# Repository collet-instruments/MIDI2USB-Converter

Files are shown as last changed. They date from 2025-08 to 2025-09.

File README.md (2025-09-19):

# 🎹 MIDI2USB Converter

<p align="center">
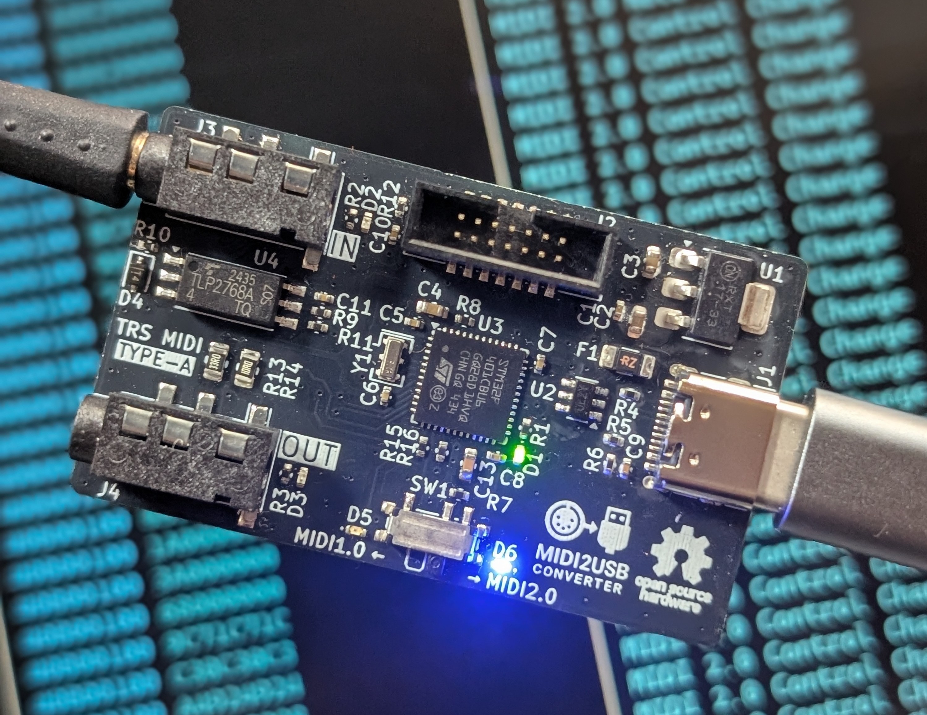
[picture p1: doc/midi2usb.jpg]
MIDI2USB Logo
  
</p>

<p align="center">
  
  
  
  
  
  
  
  
</p>

<p align="center">
  <strong>STM32F401-based USB MIDI converter supporting both MIDI 1.0 and MIDI 2.0 protocols.</strong>
</p>

## ✨ Features
- 🎵 **Dual Protocol Support**: MIDI 1.0 and MIDI 2.0 protocols
- 🔌 **USB Device Classes**: 
  - MIDI 1.0: Standard USB MIDI Class
  - MIDI 2.0: USB MIDI 2.0 Class with UMP support
- 🔄 **Dynamic Mode Switching**: Automatic detection based on SETUP switch
- 📦 **UMP (Universal MIDI Packet)**: Full support for MIDI 2.0 messaging
- 🔍 **MIDI-CI**: MIDI-CI v1.2 support
- 💡 **Visual Feedback**: LED status indicators
  - Red LED: USB MIDI 1.0 mode indicator
  - Blue LED: USB MIDI 2.0 mode indicator
- ⚡ **Real-time OS**: FreeRTOS-based multitasking
- 🔗 **UART Bridge**: Hardware TRS MIDI Type-A (3.5mm jack) interface support

## 📖 Usage

### Using USB MIDI1.0 Mode

  MIDI1.0 mode

- Switch SETUP (SW1) to MIDI1.0 and connect the USB Type-C port (J1) to a USB host
- The red LED (D5) will light up
- MIDI packets received at the MIDI IN port (J3) will be sent to the USB host
- Similarly, MIDI packets sent from the USB host will be output to the MIDI OUT port (J4)
- Data transfer status can be monitored via indicator LEDs (D2, D3) for both MIDI IN and MIDI OUT ports

### Using USB MIDI2.0 Mode

  MIDI2.0 mode

- Switch SETUP (SW1) to MIDI2.0 and connect the USB Type-C port (J1) to a USB host
- The blue LED (D6) will light up
- MIDI packets (MIDI1.0 byte stream) received at the MIDI IN port (J3) are converted to USB MIDI2.0 UMP (Universal MIDI Packet) and sent to the USB host
  - At this time, MIDI1.0 Voice Messages are extended to MIDI2.0 Protocol (UMP Message Type 4)
  - Similarly, MIDI2.0 UMP sent from the USB host is converted to MIDI1.0 byte stream and output to the MIDI OUT port (J4)
    - Since MIDI2.0 Protocol sent from the USB host is converted to MIDI1.0 Protocol, some data may be lost
- Data transfer status can be monitored via indicator LEDs (D2, D3) for both MIDI IN and MIDI OUT ports
- Some operating systems do not support USB MIDI2.0 drivers, in which case MIDI2.0 mode may not be available. Please use MIDI1.0 mode in such cases.

## 🔄 Protocol Conversion Rules

### MIDI 1.0 → MIDI 2.0 Conversion
The converter performs a 2-stage conversion process:
1. **Stage 1**: MIDI 1.0 byte stream → UMP (MIDI 1.0 Protocol)
2. **Stage 2**: UMP (MIDI 1.0 Protocol) → UMP (MIDI 2.0 Protocol)

**Key transformations**:
- **Resolution Enhancement**: 7-bit values are scaled up to 16-bit or 32-bit
  - Note velocity: 7-bit → 16-bit (e.g., 127 → ~65024)
  - Control Change values: 7-bit → 32-bit
  - Pitch Bend: 14-bit → 32-bit
- **Message Type**: Voice Messages are upgraded to UMP Message Type 4 (MIDI 2.0 Protocol)

### MIDI 2.0 → MIDI 1.0 Conversion
Direct conversion from UMP to MIDI 1.0 byte stream:

**Key transformations**:
- **Resolution Reduction**: High-resolution values are scaled down
  - Control values: 32-bit → 7-bit
- **Special handling for Note On velocity 0**:
  - In MIDI 2.0, Note On with velocity 0 remains a Note On
  - During conversion, velocity 0 is changed to 1 to prevent unintended Note Off behavior in MIDI 1.0
- **Data Loss**: MIDI 2.0-specific features (extended CC, per-note controllers) cannot be represented in MIDI 1.0

### Conversion Examples
- **MIDI 1.0 Note On**: `90 3C 64` (Ch1, Middle C, Velocity 100)
  → **MIDI 2.0 UMP**: `40902C00 32800000` (Velocity ≈ 51200)
  
- **MIDI 2.0 Note On**: Velocity 32768 (50% intensity)
  → **MIDI 1.0**: `90 3C 40` (Velocity 64, precision reduced)

## ⚠️ Caution

- The IN/OUT terminals of this product are **TRS MIDI Type-A only**. Do not use other types of cables.  
- Make sure not to confuse IN and OUT connections. Incorrect wiring may cause reverse current and damage your equipment.  
- This product is designed for **USB Type-C 5V power supply only**. Do not apply any other voltage.  
- The product may be damaged by static electricity. Please handle with proper ESD precautions.  
- Modifications or improper soldering may cause malfunction or accidents.  
- Do not use in environments with high temperature, high humidity, direct sunlight, or condensation.  
- Compatibility with all MIDI devices is **not guaranteed**.  

## 📜 Disclaimer

- This product is provided for **electronic hobby, educational, and research purposes**.  
- It is **not a consumer-ready product** and has **not been certified** under any safety standards or regulations (such as **PSE, Radio Act certification, CE, UL**, etc.).  
- By purchasing and using this product, you agree to the following terms:

### Use at Your Own Risk
- We accept no responsibility for any damage to equipment, personal injury, fire, data loss, or any other loss or accident resulting from the use of this product.

### Limitations of Use
- Do not use this product in industrial equipment, medical devices, safety systems, or any other applications where human life or property may be at risk.  
- Continuous long-term operation or use under heavy loads is not intended.

### Modification and Connections
- We are not responsible for any malfunction or damage caused by modification of this product or connection to unintended devices.

### Returns and Warranty
- If a manufacturing defect is confirmed, we will provide a replacement or refund.  
- No other warranties or guarantees are offered.

## ⚙️ Modification and Collaboration

- This product is provided as **open hardware**.  
  You are free to modify, reuse, or build upon the circuit and firmware.  
  However, **we cannot guarantee the operation or safety of modified versions**.  

- We welcome contributions from developers and users who wish to improve the design.  
  Please feel free to share feedback, modifications, or enhancement ideas.  

## 🛠️ Build Requirements

- ARM GCC toolchain (arm-none-eabi-gcc)
- CMake (3.22 or later)
- Ninja build system
- Git (for submodules)

## 📥 Getting Started

### Clone the Repository

```bash
git clone --recursive https://github.com/collet-instruments/MIDI2USB-Converter.git
cd MIDI2USB-Converter

# If you already cloned without --recursive, initialize submodules
git submodule init
git submodule update
```
### IDE Integration

**VS Code**: Use CMake extension for building and debugging with ST-Link.

- [STM32 VS Code extension](https://www.st.com/content/st_com/ja/campaigns/stm32-vs-code-extension-z11.html) makes setup easy.

## 🔨 Building

### Using CMake

```bash
# Configure the project
cmake --preset Debug

# Build the firmware
cmake --build --preset Debug

# The output files will be in build/Debug/
```
### Build Configurations

The project supports multiple build configurations:

- **Debug**: Development build with debug symbols (default)
- **Release**: Optimized build for production (-O2 optimization)
- **RelWithDebInfo**: Release build with debug info
- **MinSizeRel**: Size-optimized build (-Os optimization)

## 🧪 Testing

The project includes a comprehensive unit test suite using Unity framework.

### Running Tests

```bash
# Run all tests
cd test
make test

# Run specific test
make test-mode_manager

# Run tests with coverage
make clean
make COVERAGE=1
make test
```

## ✅ Code Quality

### Code Formatting

The project uses clang-format for code formatting. Configuration is in `.clang-format`.

```bash
# Format code
clang-format -i Core/Src/*.c Core/Inc/*.h

# Check formatting without modifying files
clang-format --dry-run --Werror Core/Src/*.c Core/Inc/*.h
```

### Static Analysis

```bash
# Run cppcheck
cppcheck --enable=warning,style,performance,portability \
  -I Core/Inc \
  Core/Src/
```

### CI/CD

GitHub Actions automatically runs on every push and pull request:

#### Workflows:
- **ci.yml**: Main CI pipeline
  - Builds STM32 firmware  
  - Runs all unit tests
  - Uploads firmware artifacts
  
- **code-quality.yml**: Code quality checks
  - Static analysis with cppcheck
  - Code formatting verification with clang-format
  
- **release.yml**: Automated releases
  - Triggers on version tags (v*)
  - Creates GitHub releases with firmware binaries

## 📁 Project Structure

```
├── Core/               # Application source code
├── Drivers/            # STM32 HAL and CMSIS drivers
├── submodules/         # External dependencies
│   ├── FreeRTOS-Kernel/
│   ├── tinyusb/
│   ├── AM_MIDI2.0Lib/
│   ├── tusb_ump/
│   └── Unity/
├── test/               # Unit tests (Unity framework)
│   ├── src/            # Test source files
│   ├── mock/           # Mock implementations
│   └── include/        # Test headers
├── ci/                 # CI/CD scripts
└── .github/            # CI/CD workflows
```

## 📦 Submodules

This project uses the following Git submodules:

| Submodule | Repository URL | Description |
|---|---|---|
| **FreeRTOS-Kernel** | https://github.com/FreeRTOS/FreeRTOS-Kernel.git | FreeRTOS kernel files only |
| **tinyusb** | https://github.com/hathach/tinyusb.git | An open source cross-platform USB stack for embedded system |
| **tusb_ump** | https://github.com/midi2-dev/tusb_ump | USB MIDI 2.0 tinyUSB Device driver with backwards compatibility to USB MIDI 1.0 |
| **AM_MIDI2.0Lib** | https://github.com/midi2-dev/AM_MIDI2.0Lib | A MIDI 2.0 C++ Library |
| **Unity** | https://github.com/ThrowTheSwitch/Unity.git | Simple unit testing for C |

## 🔧 Hardware

### 🎛️ Microcontroller
- **MCU**: STM32F401CBU6 (ARM Cortex-M4, 84MHz)
- **Flash**: 256KB
- **RAM**: 64KB

### 🔌 Interfaces
- **USB**: Full-Speed USB 2.0 (12Mbps)
- **UART**: MIDI serial interface (31.25 kbaud)
  - TX: PA2 (USART2_TX)
  - RX: PA3 (USART2_RX)
- **DEBUG**: ST-Link support (J2 connector)

### 📍 GPIO Pins
- **Mode Selection**: PA5 (SETUP pin)
  - High: USB MIDI 2.0 mode
  - Low: USB MIDI 1.0 mode
- **LEDs**:
  - M1LED: PA4 - USB MIDI 1.0 mode indicator
  - M2LED: PA6 - USB MIDI 2.0 mode indicator

### ⚡ Power
- Powered via USB (5V)
- 3.3V internal operation

## 💻 Development

### Running Tests Locally
```bash
# Quick test before pushing
./ci/test-ci-locally.sh

# Install optional CI tools
./ci/install-ci-tools.sh
```

### Debugging

1. **VS Code**: Use CMake extension and ST-Link for debugging
2. **OpenOCD**: Manual debugging with GDB

- Connect the J2 connector (NRST, SYS_SWCLK, SYS_SWDIO) to ST-Link for debugging. USART1 is also available for printf debugging.

## 🤝 Contributing

We welcome contributions! Please see [CONTRIBUTING.md](CONTRIBUTING.md) for details on:
- How to submit issues
- How to submit pull requests
- Code style guidelines
- Development setup

## 📜 Code of Conduct

This project adheres to a Code of Conduct. By participating, you are expected to uphold this code. Please see [CODE_OF_CONDUCT.md](CODE_OF_CONDUCT.md) for details.

## 📄 License

This project is licensed under the MIT License - see the [LICENSE](LICENSE) file for details.

**Hardware Design**: All hardware design files including schematics, PCB layouts, and manufacturing files in the `hardware/` directory are also covered under the same MIT License.

### Third-party Licenses

This project uses the following open-source libraries:
- **FreeRTOS-Kernel**: MIT License
- **TinyUSB**: MIT License
- **AM_MIDI2.0Lib**: MIT License
- **Unity Test Framework**: MIT License
- **STM32 HAL Drivers**: BSD 3-Clause License (STMicroelectronics)

## 👥 Authors and Acknowledgments

- USB MIDI 2.0 implementation based on TinyUSB and AM_MIDI2.0Lib
- STM32 HAL drivers by STMicroelectronics
- Special thanks to all contributors

## 💬 Support

For questions and support:
- Open an issue on GitHub
- Check existing issues and discussions
- See documentation in the repository

## 📝 Copyright

Copyright © 2025 Collet Instruments. All rights reserved.

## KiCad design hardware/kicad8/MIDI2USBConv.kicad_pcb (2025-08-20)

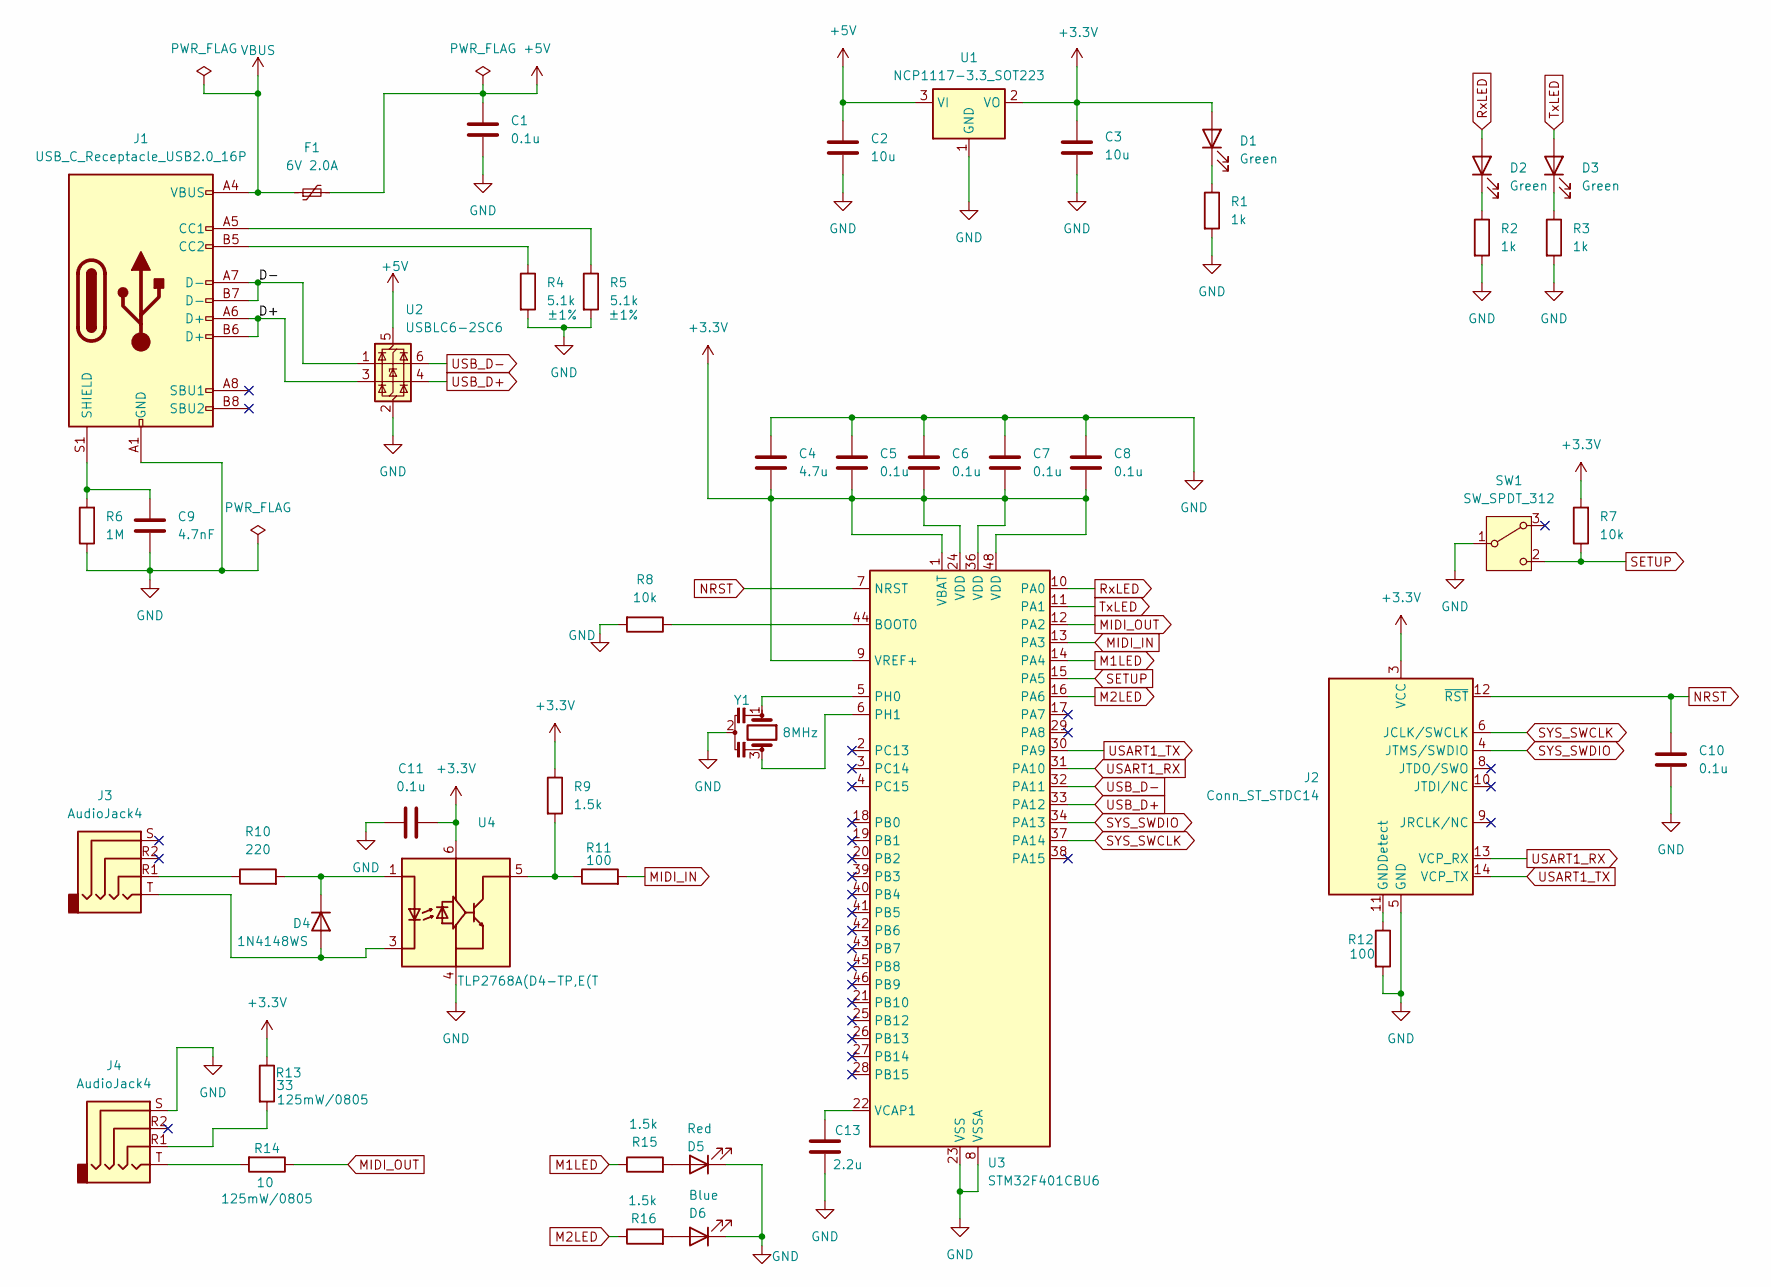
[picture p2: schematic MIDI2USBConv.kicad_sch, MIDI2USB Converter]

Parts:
C1, C5, C6, C7, C8, C10, C11: 0.1u; C_0402_1005Metric; LCSC C1525
C2, C3: 10u; C_0603_1608Metric; LCSC C1691
C4: 4.7u; C_0603_1608Metric; LCSC C1705
C9: 4.7nF; C_0402_1005Metric; LCSC C1538
C13: 2.2u; C_0603_1608Metric; LCSC C1607
D1, D2, D3: Green; LED_0402_1005Metric; LCSC C434449
D4: 1N4148WS; D_SOD-323; LCSC C2128
D5: Red; LED_0402_1005Metric; LCSC C264407
D6: Blue; LED_0402_1005Metric; LCSC C131223
F1: 6V 2.0A; Fuse_1206_3216Metric; LCSC C20803
J1: USB_C_Receptacle_USB2.0_16P; USB_C_Receptacle_G-Switch_GT-USB-7010ASV; LCSC C2988369
J2: Conn_ST_STDC14; STDC14_SMD; LCSC C42455944
J3, J4: AudioJack4; Jack_3.5mm_PJ320D_Horizontal; LCSC C95562
R1, R2, R3: 1k; R_0402_1005Metric; LCSC C11702
R4, R5: 5.1k; R_0402_1005Metric; LCSC C25905
R6: 1M; R_0402_1005Metric; LCSC C26083
R7, R8: 10k; R_0402_1005Metric; LCSC C25531
R9, R15, R16: 1.5k; R_0402_1005Metric; LCSC C25867
R10: 220; R_0402_1005Metric; LCSC C25091
R11, R12: 100; R_0402_1005Metric; LCSC C25076
R13: 33; R_0805_2012Metric; LCSC C17634
R14: 10; R_0805_2012Metric; LCSC C17415
SW1: SW_SPDT_312; SW_SPDT_PCM12; LCSC C221841
U1: NCP1117-3.3_SOT223; SOT-223-3_TabPin2; LCSC C26537
U2: USBLC6-2SC6; SOT-23-6; LCSC C5310974
U3: STM32F401CBU6; QFN-48-1EP_7x7mm_P0.5mm_EP5.6x5.6mm; LCSC C118825
U4: TLP2768A(D4-TP,E(T; SO-6L_10x3.84mm_P1.27mm; LCSC C5370532
Y1: 8MHz; Resonator_SMD_Murata_CSTxExxV-3Pin_3.0x1.1mm; LCSC C341524

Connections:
+3.3V: C3.1, C4.2, C5.2, C6.2, C7.2, C8.2, C11.2, D1.2 (A), J2.3 (VCC), R7.2, R9.1, R13.1, U1.2 (VO), U3.1 (VBAT), U3.9 (VREF+), U3.24 (VDD), U3.36 (VDD), U3.48 (VDD), U4.6 (VDD)
+5V: C1.1, C2.1, F1.2, U1.3 (VI), U2.5 (VBUS)
/D+: J1.A6 (D+), J1.B6 (D+), U2.3 (I/O2)
/D-: J1.A7 (D-), J1.B7 (D-), U2.1 (I/O1)
GND: C1.2, C2.2, C3.2, C4.1, C5.1, C6.1, C7.1, C8.1, C9.1, C10.2, C11.1, C13.2, D5.1 (K), D6.1 (K), J1.A1 (GND), J1.A12 (GND), J1.B1 (GND), J1.B12 (GND), J2.5 (GND), J2.7 (GND), J4.S, R1.2, R2.2, R3.2, R4.2, R5.2, R6.1, R8.2, R12.2, SW1.1 (B), U1.1 (GND), U2.2 (GND), U3.8 (VSSA), U3.23 (VSS), U3.35 (VSS), U3.47 (VSS), U3.49 (VSS), U4.4 (GND), Y1.2
M1LED: R15.1, U3.14 (PA4)
M2LED: R16.1, U3.16 (PA6)
MIDI_IN: R11.2, U3.13 (PA3)
MIDI_OUT: R14.1, U3.12 (PA2)
NRST: C10.1, J2.12 (~RST), U3.7 (NRST)
unnamed: D1.1 (K), R1.1
unnamed: D2.1 (K), R2.1
unnamed: D3.1 (K), R3.1
unnamed: D4.2 (A), J3.T, U4.3 (K)
unnamed: D4.1 (K), R10.2, U4.1 (A)
unnamed: D5.2 (A), R15.2
unnamed: D6.2 (A), R16.2
unnamed: J1.A5 (CC1), R5.1
unnamed: J1.B5 (CC2), R4.1
unnamed: C9.2, J1.S1 (SHIELD), R6.2
unnamed: J2.11 (GNDDetect), R12.1
unnamed: J3.R1, R10.1
unnamed: J4.R1, R13.2
unnamed: J4.T, R14.2
unnamed: R8.1, U3.44 (BOOT0)
unnamed: U3.5 (PH0), Y1.1
unnamed: U3.6 (PH1), Y1.3
unnamed: C13.1, U3.22 (VCAP1)
unnamed: R9.2, R11.1, U4.5 (VO)
RxLED: D2.2 (A), U3.10 (PA0)
SETUP: R7.1, SW1.2 (C), U3.15 (PA5)
SYS_SWCLK: J2.6 (JCLK/SWCLK), U3.37 (PA14)
SYS_SWDIO: J2.4 (JTMS/SWDIO), U3.34 (PA13)
TxLED: D3.2 (A), U3.11 (PA1)
USART1_RX: J2.13 (VCP_RX), U3.31 (PA10)
USART1_TX: J2.14 (VCP_TX), U3.30 (PA9)
USB_D+: U2.4 (I/O2), U3.33 (PA12)
USB_D-: U2.6 (I/O1), U3.32 (PA11)
VBUS: F1.1, J1.A4 (VBUS), J1.A9 (VBUS), J1.B4 (VBUS), J1.B9 (VBUS)

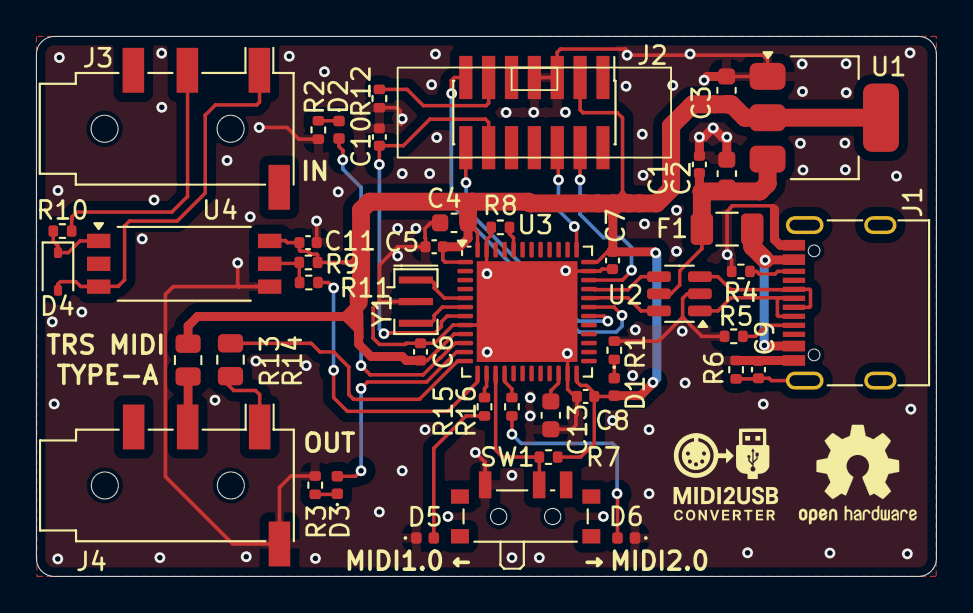
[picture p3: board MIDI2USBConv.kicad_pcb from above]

Board: 2 copper layers, 50.0 x 30.0 mm, 45 parts (0 on the bottom side), 39 nets.

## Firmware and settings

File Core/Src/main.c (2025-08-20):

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
/* Includes ------------------------------------------------------------------*/
#include "main.h"

/* USER CODE BEGIN Includes */
#include "FreeRTOS.h"
#include "task.h"
#include "queue.h"
#include "tusb.h"
#include "led_task.h"
#include "usb_device_task.h"
#include "usb_midi_task.h"
#include "uart_midi_task.h"
#include "midi_common.h"
#include "mode_manager.h"
#include "midi2_task.h"
#include "app_ump_device.h"
#include "ump_task.h"
#include "ump_discovery.h"
/* USER CODE END Includes */

/* USER CODE BEGIN PD */
// FreeRTOS Task Configuration
#define TASK_PRIORITY_LED           1
#define TASK_PRIORITY_MIDI_NORMAL   3
#define TASK_PRIORITY_USB_RX        (configMAX_PRIORITIES-2)
#define TASK_PRIORITY_USB_DEVICE    (configMAX_PRIORITIES-1)

#define TASK_STACK_LED              128   // Minimal for LED control
#define TASK_STACK_USB_DEVICE       512   // Sufficient for TinyUSB operations
#define TASK_STACK_MIDI             256   // Sufficient for MIDI processing
/* USER CODE END PD */

UART_HandleTypeDef huart1;
UART_HandleTypeDef huart2;
DMA_HandleTypeDef hdma_usart2_rx;
DMA_HandleTypeDef hdma_usart2_tx;

PCD_HandleTypeDef hpcd_USB_OTG_FS;

void SystemClock_Config(void);
static void MX_GPIO_Init(void);
static void MX_DMA_Init(void);
static void MX_USART1_UART_Init(void);
static void MX_USART2_UART_Init(void);
static void MX_USB_OTG_FS_PCD_Init(void);
/* USER CODE BEGIN PFP */
static BaseType_t MIDI_CreateTasks(void);
/* USER CODE END PFP */

/**
  * @brief  The application entry point.
  * @retval int
  */
int main(void)
{

  /* MCU Configuration--------------------------------------------------------*/

  /* Reset of all peripherals, Initializes the Flash interface and the Systick. */
  HAL_Init();

  /* Configure the system clock */
  SystemClock_Config();

  /* Initialize all configured peripherals */
  MX_GPIO_Init();
  MX_DMA_Init();
  MX_USART1_UART_Init();
  MX_USART2_UART_Init();
  MX_USB_OTG_FS_PCD_Init();
  /* USER CODE BEGIN 2 */

  /* Initialize mode manager */
  ModeManager_Init();
  
  /* Initialize MIDI system */
  if (MIDI_InitQueues() != pdPASS) {
    /* Failed to create queues - enter error state */
    Error_Handler();
  }
  
  /* Initialize UART TX DMA */
  UART_TX_DMA_Init();

  /* Initialize MIDI 2.0 system if in MIDI 2.0 mode */
  if (ModeManager_GetMode() == MIDI_MODE_2_0) {
    if (MIDI2_InitQueues() != pdPASS) {
      /* Failed to create MIDI 2.0 queues - enter error state */
      Error_Handler();
    }
    
    /* Initialize UMP Discovery */
    UMP_Discovery_Init();
  }

  /* Create and start all tasks */
  if (MIDI_CreateTasks() != pdPASS) {
    /* Failed to create tasks - enter error state */
    Error_Handler();
  }

  /* Start the FreeRTOS scheduler */
  vTaskStartScheduler();

  /* USER CODE END 2 */

  /* Infinite loop */
  /* USER CODE BEGIN WHILE */
  while (1)
  {
    /* USER CODE END WHILE */

    /* USER CODE BEGIN 3 */
  }
  /* USER CODE END 3 */
}

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
/* USER CODE BEGIN 4 */
/**
  * @brief Create all MIDI-related FreeRTOS tasks
  * @retval pdPASS if all tasks created successfully, pdFAIL otherwise
  */
static BaseType_t MIDI_CreateTasks(void) {
  BaseType_t xReturned;
  MidiMode_t current_mode = ModeManager_GetMode();
  
  // LED task for status indication
  xReturned = xTaskCreate(vLEDBlinkTask, "led", TASK_STACK_LED, NULL, TASK_PRIORITY_LED, NULL);
  if (xReturned != pdPASS) return pdFAIL;
  
  // USB-related tasks
  xReturned = xTaskCreate(vUSBDeviceTask, "usbd", TASK_STACK_USB_DEVICE, NULL, TASK_PRIORITY_USB_DEVICE, NULL);
  if (xReturned != pdPASS) return pdFAIL;
  
  // UART-related tasks
  xReturned = xTaskCreate(vUartRxMidiTask, "uart_rx", TASK_STACK_MIDI, NULL, TASK_PRIORITY_MIDI_NORMAL, NULL);
  if (xReturned != pdPASS) return pdFAIL;
  
  if (current_mode == MIDI_MODE_1_0) {
    // MIDI 1.0 mode: use original tasks
    xReturned = xTaskCreate(vUsbToUartTask, "usb2uart", TASK_STACK_MIDI, NULL, TASK_PRIORITY_MIDI_NORMAL, NULL);
    if (xReturned != pdPASS) return pdFAIL;
    
    xReturned = xTaskCreate(vUsbRxMidiTask, "usb_rx", TASK_STACK_MIDI, NULL, TASK_PRIORITY_USB_RX, NULL);
    if (xReturned != pdPASS) return pdFAIL;
    
    xReturned = xTaskCreate(vUartToUsbTask, "uart2usb", TASK_STACK_MIDI, NULL, TASK_PRIORITY_MIDI_NORMAL, NULL);
    if (xReturned != pdPASS) return pdFAIL;
  } else {
    // MIDI 2.0 mode: use UMP conversion tasks
    xReturned = xTaskCreate(vMidi2UartToUmpTask, "uart2ump", TASK_STACK_MIDI, NULL, TASK_PRIORITY_MIDI_NORMAL, NULL);
    if (xReturned != pdPASS) return pdFAIL;
    
    xReturned = xTaskCreate(vMidi2UmpToUartTask, "ump2uart", TASK_STACK_MIDI, NULL, TASK_PRIORITY_MIDI_NORMAL, NULL);
    if (xReturned != pdPASS) return pdFAIL;
    
    // UMP USB communication tasks
    xReturned = xTaskCreate(vUmpToUsbTask, "ump2usb", TASK_STACK_MIDI, NULL, TASK_PRIORITY_MIDI_NORMAL, NULL);
    if (xReturned != pdPASS) return pdFAIL;
    
    xReturned = xTaskCreate(vUsbToUmpTask, "usb2ump", TASK_STACK_MIDI, NULL, TASK_PRIORITY_USB_RX, NULL);
    if (xReturned != pdPASS) return pdFAIL;
  }
  
  return pdPASS;
}
/* USER CODE END 4 */

/**
  * @brief  Period elapsed callback in non blocking mode
  * @note   This function is called  when TIM1 interrupt took place, inside
  * HAL_TIM_IRQHandler(). It makes a direct call to HAL_IncTick() to increment
  * a global variable "uwTick" used as application time base.
  * @param  htim : TIM handle
  * @retval None
  */
void HAL_TIM_PeriodElapsedCallback(TIM_HandleTypeDef *htim)
{
  if (htim->Instance == TIM1)
  {
    HAL_IncTick();
  }
}

/**
  * @brief  This function is executed in case of error occurrence.
  * @retval None
  */
void Error_Handler(void)
{
  /* USER CODE BEGIN Error_Handler_Debug */
  /* User can add his own implementation to report the HAL error return state */
  __disable_irq();
  while (1)
  {
  }
  /* USER CODE END Error_Handler_Debug */
}

#ifdef  USE_FULL_ASSERT
/**
  * @brief  Reports the name of the source file and the source line number
  *         where the assert_param error has occurred.
  * @param  file: pointer to the source file name
  * @param  line: assert_param error line source number
  * @retval None
  */
void assert_failed(uint8_t *file, uint32_t line)
{
  /* USER CODE BEGIN 6 */
  /* User can add his own implementation to report the file name and line number,
     ex: printf("Wrong parameters value: file %s on line %d\r\n", file, line) */
  /* USER CODE END 6 */
}
#endif /* USE_FULL_ASSERT */

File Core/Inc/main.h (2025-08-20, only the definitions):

#define RxMIDI_Pin GPIO_PIN_0
#define RxMIDI_GPIO_Port GPIOA
#define TxMIDI_Pin GPIO_PIN_1
#define TxMIDI_GPIO_Port GPIOA
#define MIDI_OUT_Pin GPIO_PIN_2
#define MIDI_OUT_GPIO_Port GPIOA
#define MIDI_IN_Pin GPIO_PIN_3
#define MIDI_IN_GPIO_Port GPIOA
#define M1LED_Pin GPIO_PIN_4
#define M1LED_GPIO_Port GPIOA
#define SETUP_Pin GPIO_PIN_5
#define SETUP_GPIO_Port GPIOA
#define M2LED_Pin GPIO_PIN_6
#define M2LED_GPIO_Port GPIOA

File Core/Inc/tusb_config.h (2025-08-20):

/**
 * @file           : tusb_config.h
 * @brief          : TinyUSB configuration for USB MIDI device
 * @note           : Based on TinyUSB template (github.com/hathach/tinyusb)
 */

#ifndef _TUSB_CONFIG_H_
#define _TUSB_CONFIG_H_

#ifdef __cplusplus
 extern "C" {
#endif

// Function declaration for dynamic mode switching
#ifndef __cplusplus
#include <stdbool.h>
extern bool is_midi2_mode(void);
#endif

//--------------------------------------------------------------------+
// Board Specific Configuration
//--------------------------------------------------------------------+

// RHPort number used for device can be defined by board.mk, default to port 0
#ifndef BOARD_TUD_RHPORT
#define BOARD_TUD_RHPORT      0
#endif

// RHPort max operational speed can defined by board.mk
#ifndef BOARD_TUD_MAX_SPEED
#define BOARD_TUD_MAX_SPEED   OPT_MODE_FULL_SPEED
#endif

//--------------------------------------------------------------------
// COMMON CONFIGURATION
//--------------------------------------------------------------------

// defined by compiler flags for flexibility
#define CFG_TUSB_MCU          OPT_MCU_STM32F4
#define CFG_TUSB_OS           OPT_OS_FREERTOS

#ifndef CFG_TUSB_DEBUG
#define CFG_TUSB_DEBUG        0
#endif

// Enable Device stack
#define CFG_TUD_ENABLED       1

// Default is max speed that hardware controller could support with on-chip PHY
#define CFG_TUD_MAX_SPEED     BOARD_TUD_MAX_SPEED

/* USB DMA on some MCUs can only access a specific SRAM region with restriction on alignment.
 * Tinyusb use follows macros to declare transferring memory so that they can be put
 * into those specific section.
 * e.g
 * - CFG_TUSB_MEM SECTION : __attribute__ (( section(".usb_ram") ))
 * - CFG_TUSB_MEM_ALIGN   : __attribute__ ((aligned(4)))
 */
#ifndef CFG_TUSB_MEM_SECTION
#define CFG_TUSB_MEM_SECTION
#endif

#ifndef CFG_TUSB_MEM_ALIGN
#define CFG_TUSB_MEM_ALIGN        __attribute__ ((aligned(4)))
#endif

//--------------------------------------------------------------------
// DEVICE CONFIGURATION
//--------------------------------------------------------------------

#ifndef CFG_TUD_ENDPOINT0_SIZE
#define CFG_TUD_ENDPOINT0_SIZE    64
#endif

//------------- CLASS -------------//
#define CFG_TUD_CDC               0
#define CFG_TUD_MSC               0
#define CFG_TUD_HID               0
#define CFG_TUD_MIDI              1
#define CFG_TUD_UMP               1
#define CFG_TUD_VENDOR            0

// MIDI FIFO size of TX and RX
#define CFG_TUD_MIDI_RX_BUFSIZE   512
#define CFG_TUD_MIDI_TX_BUFSIZE   512

#define CFG_TUD_UMP_RX_BUFSIZE  512
#define CFG_TUD_UMP_TX_BUFSIZE   512

#define TUD_OPT_RHPORT 0

#ifdef __cplusplus
 }
#endif

#endif /* _TUSB_CONFIG_H_ */

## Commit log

2025-08-20 Add project files and CI/CD setup
    [MIDI2USBConv.kicad_pcb, MIDI2USBConv.kicad_sch]
2025-09-18 fix: implement MIDI filtering at conversion and transmission stages
    [midi2_task.c, uart_midi_task.c]

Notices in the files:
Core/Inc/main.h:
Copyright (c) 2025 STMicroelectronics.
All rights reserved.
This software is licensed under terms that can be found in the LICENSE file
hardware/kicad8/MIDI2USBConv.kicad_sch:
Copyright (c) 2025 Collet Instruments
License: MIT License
